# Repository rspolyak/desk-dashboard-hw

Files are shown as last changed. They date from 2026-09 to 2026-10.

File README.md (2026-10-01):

# desk-dashboard-hw

A small ESP32-S3 board that plugs onto the 14-pin header of an **MSP3526** 3.5" IPS
capacitive touchscreen (ST7796 + FT6336U) and turns it into a desk dashboard.
Powered over USB-C (5 V). KiCad 10 project.

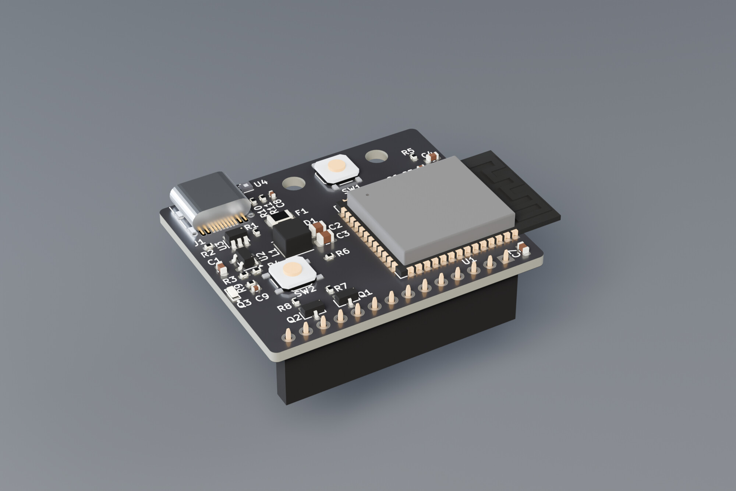
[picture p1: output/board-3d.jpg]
3D render of the board


**Status:** schematic and PCB finished (ERC 0 errors, DRC 0 errors, fully routed).
!NOT TESTED ON ACTUAL HW YET!

## Features
- ESP32-S3-WROOM-1-N16R8 (16 MB flash, 8 MB octal PSRAM), native USB on the USB-C connector
- Plugs straight into the display's 14-pin 2.54 mm header, no cables; two optional M3 standoffs
- Ambient light sensor (ALS-PT19) for automatic backlight control
- SHT40 temperature / humidity sensor on its own I²C bus
- BOOT and RESET buttons
- 5 V to 3.3 V buck (TLV62569), USB ESD protection (USBLC6-2SC6), 1.1 A PTC and TVS on VBUS

## Board
- 41.5 x 35 mm, 2 layers, 1.6 mm, black solder mask, white silkscreen
- The ESP32 antenna overhangs the right board edge by 6 mm (Espressif's preferred placement)
- J2 (display socket) is on the display-facing side; all other parts face outward

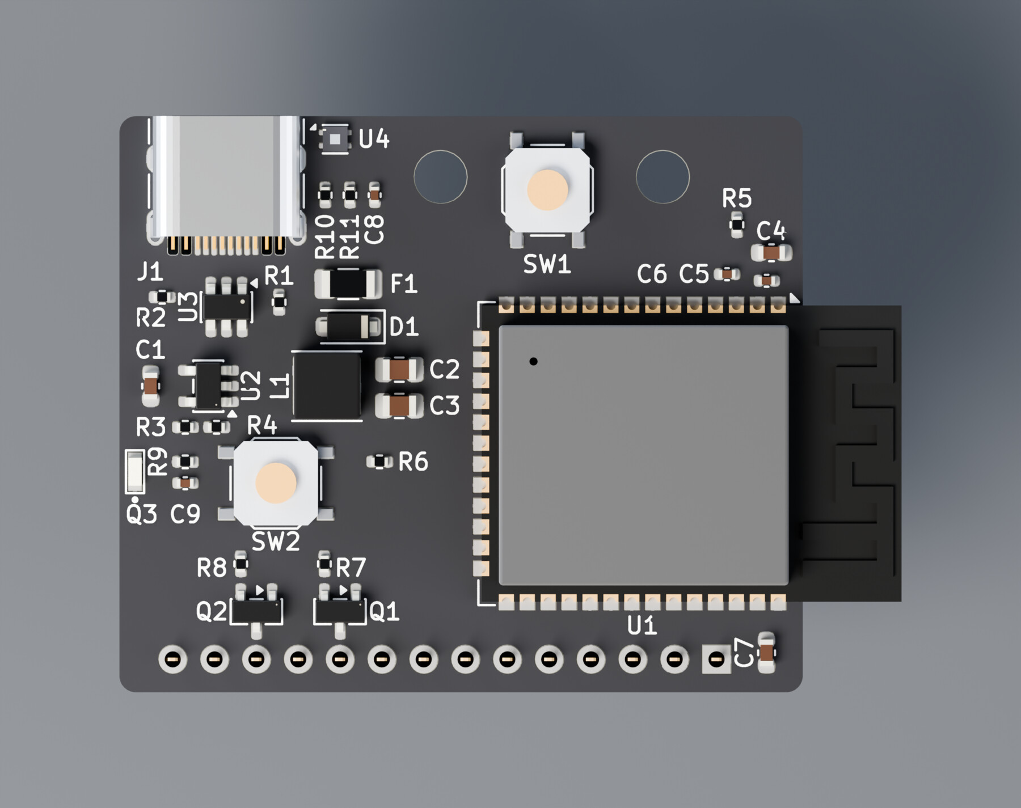
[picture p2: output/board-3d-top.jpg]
Top view of the board with all reference designators


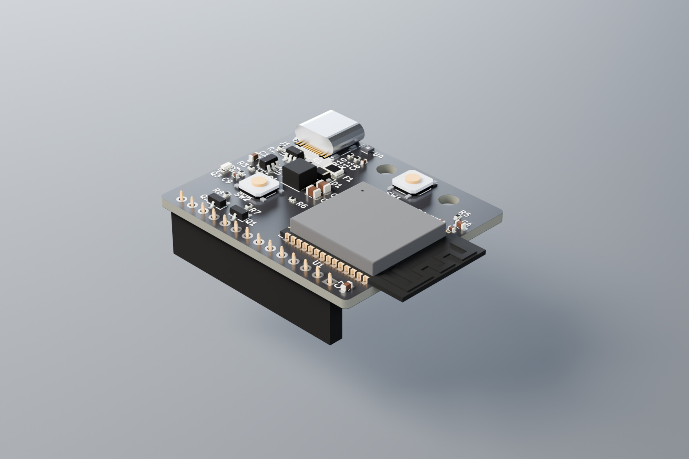
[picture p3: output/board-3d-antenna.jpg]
Side view: J2 display socket underneath and the ESP32 antenna overhanging the board edge


## Design notes
- The display is powered from **5 V**: its LDO also feeds the backlight, which would be dim at 3.3 V.
- The display's touch I²C has 10 k pull-ups to 5 V, so two BSS138 level shifters (Q1 SCL, Q2 SDA)
  keep 5 V away from the ESP32-S3.
- The SHT40 is on a separate I²C controller from the touch panel.
- The light sensor is on ADC1 (ADC2 conflicts with Wi-Fi).

## Parts
All parts were in stock at JLCPCB when the design was finished. Each schematic symbol carries an
`LCSC` field with its part number.

| Ref | Part | LCSC |
|---|---|---|
| U1 | ESP32-S3-WROOM-1-N16R8 | C2913202 |
| U2 | TLV62569DBVR | C141836 |
| U3 | USBLC6-2SC6 | C2687116 |
| U4 | SHT40-AD1B-R2 | C2909890 |
| J1 | USB-C HRO TYPE-C-31-M-12 | C165948 |
| J2 | 1x14 female header, 2.54 mm, 8.5 mm | C2897377 |
| Q1, Q2 | BSS138 | C78284 |
| Q3 | ALS-PT19-315C | C146233 |

Passives, buttons, PTC, TVS and the inductor are listed in the schematic.

## Display
LCDwiki MSP3526 (3.5" IPS, 320x480, ST7796 + FT6336U), sold by several resellers. Check that the
header pin labels match the J2 order above before buying.

## License
MIT, see LICENSE

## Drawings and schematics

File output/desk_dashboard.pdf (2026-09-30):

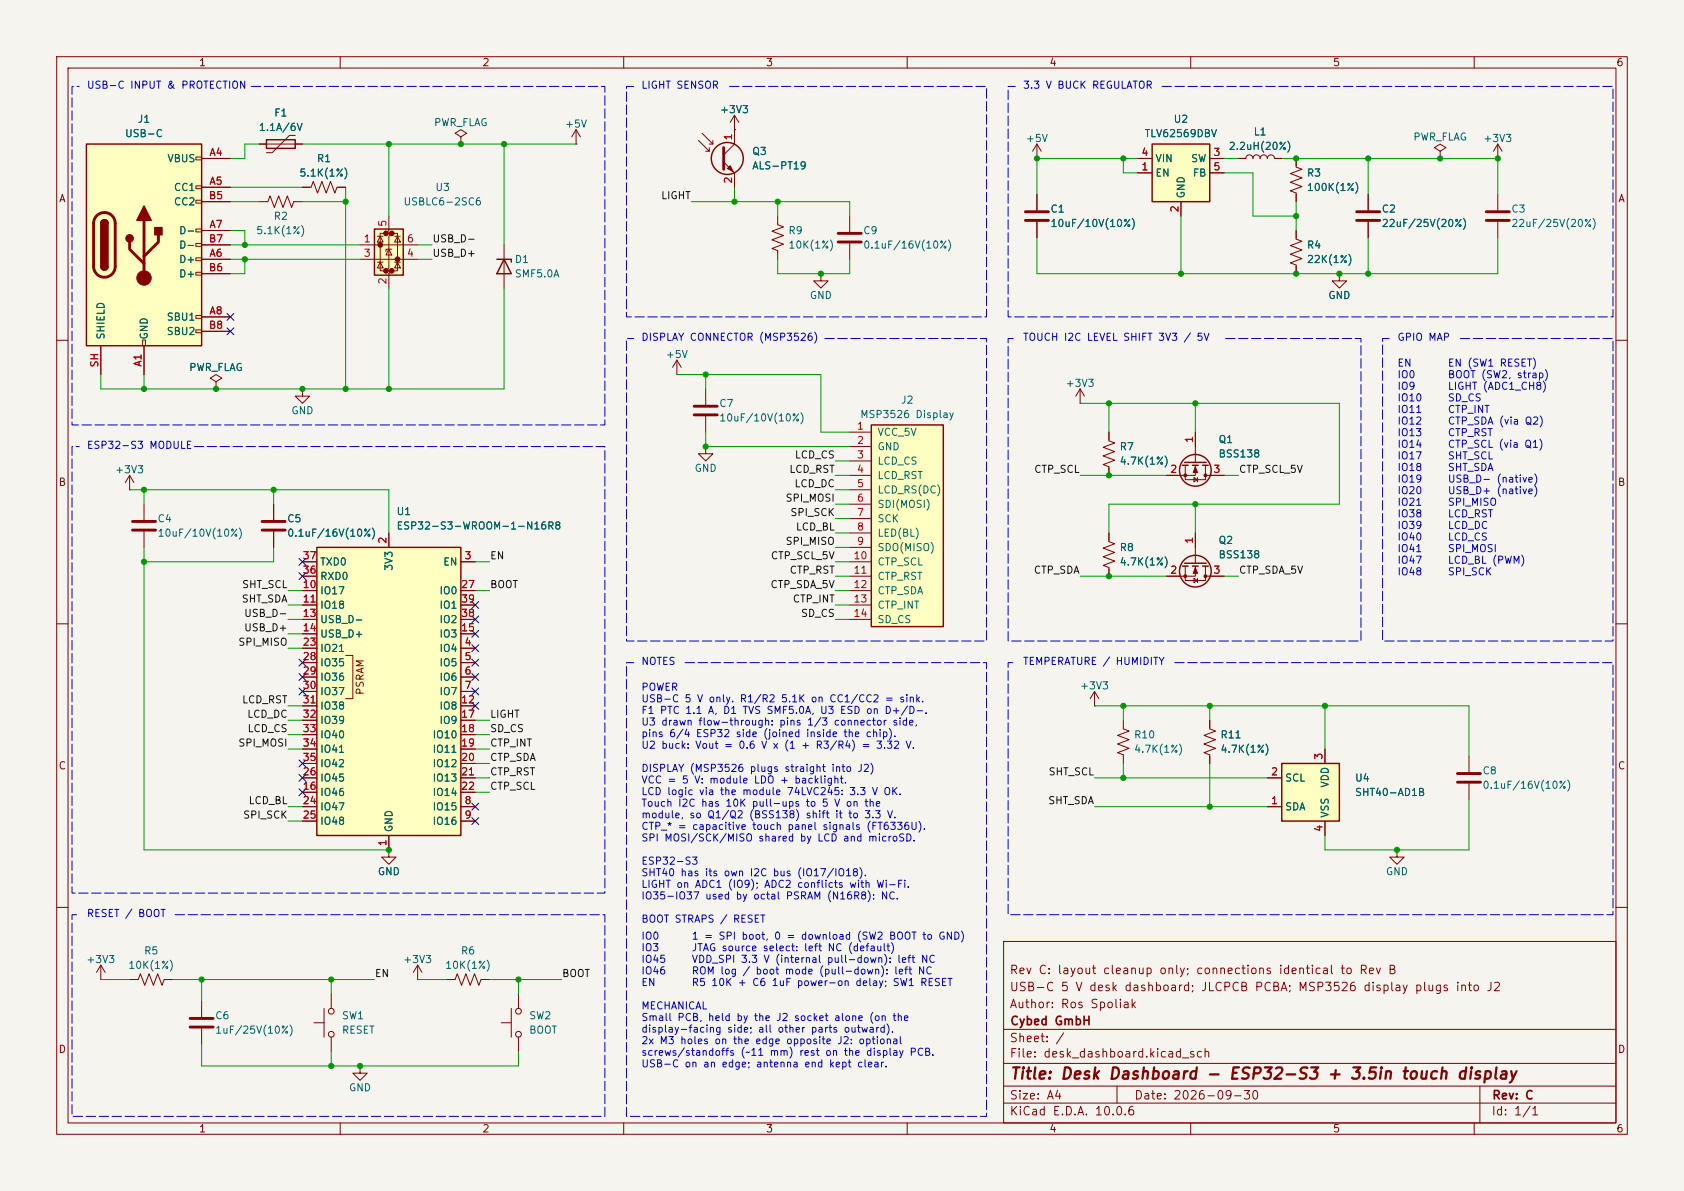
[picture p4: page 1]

EN (SW1 RESET) BOOT (SW2, strap) LIGHT (ADC1_CH8) SD_CS CTP_INT CTP_SDA (via Q2) CTP_RST CTP_SCL (via Q1) SHT_SCL SHT_SDA USB_D- (native) USB_D+ SPI_MISO

IO48 MECHANICAL Small PCB, held by the J2 socket alone (on the display-facing side; all other parts outward). 2x M3 holes on the edge opposite J2: optional

screws/standoffs (~11 mm) rest on the display PCB. USB-C on an edge; antenna end kept clear. POWER USB-C 5 V only. R1/R2 5.1K on CC1/CC2 = sink. F1 PTC 1.1 A, D1 TVS SMF5.0A, U3 ESD on D+/D-. U3 drawn flow-through: pins 1/3 connector side,

pins 6/4 ESP32 side (joined inside the chip). U2 buck: Vout = 0.6 V x (1 + R3/R4) = 3.32 V. DISPLAY (MSP3526 plugs straight into J2) VCC = 5 V: module LDO + backlight. LCD logic via the module 74LVC245: 3.3 V OK. Touch I2C has 10K pull-ups to 5 V on the module, so Q1/Q2 (BSS138) shift it to 3.3 V. CTP_* = capacitive touch panel signals (FT6336U). SPI MOSI/SCK/MISO shared by LCD and microSD. ESP32-S3

SHT40 has its own I2C bus (IO17/IO18). LIGHT on ADC1 (IO9); ADC2 conflicts with Wi-Fi.

IO35-IO37 used by octal PSRAM (N16R8): NC. BOOT STRAPS / RESET

1 = SPI boot, 0 = download (SW2 BOOT to GND) JTAG source select: left NC (default) VDD_SPI 3.3 V (internal pull-down): left NC

ROM log / boot mode (pull-down): left NC
R5 10K + C6 1uF power-on delay; SW1 RESET

Rev C: layout cleanup only; connections identical to Rev B
USB-C 5 V desk dashboard; JLCPCB PCBA; MSP3526 display plugs into J2
Author: Ros Spoliak
Cybed GmbH
Sheet: /
File: desk_dashboard.kicad_sch
Title: Desk Dashboard - ESP32-S3 + 3.5in touch display

Size: A4 | Rev: C
KiCad E.D.A. 10.0.6 | Id: 1/1

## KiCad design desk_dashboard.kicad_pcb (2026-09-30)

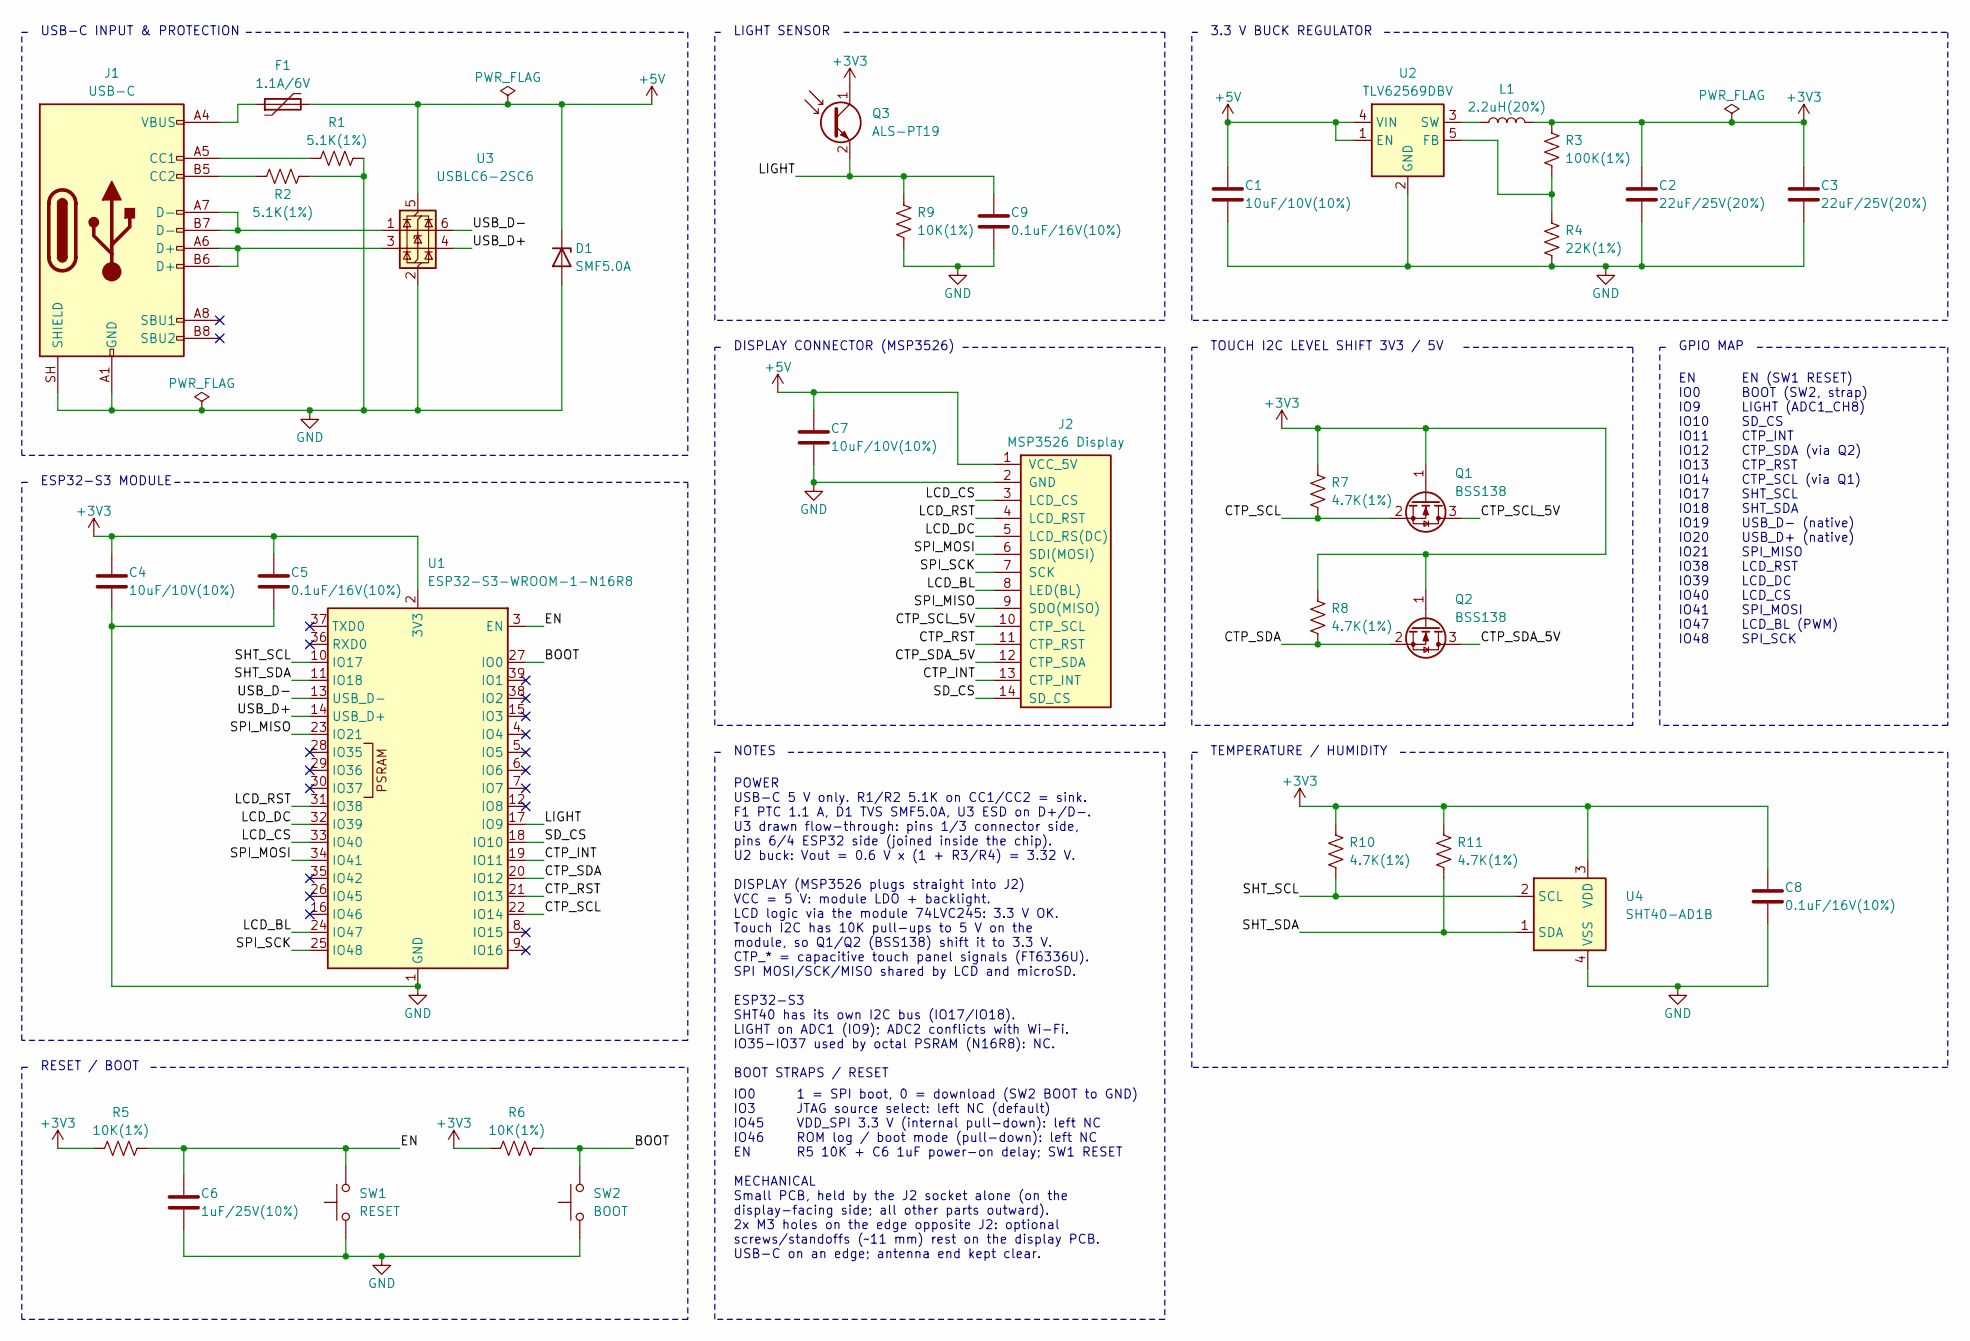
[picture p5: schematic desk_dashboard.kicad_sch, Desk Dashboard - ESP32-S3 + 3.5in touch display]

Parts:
C1, C4, C7: 10uF/10V(10%); C_0603_1608Metric; LCSC C19702
C2, C3: 22uF/25V(20%); C_0805_2012Metric; LCSC C45783
C5, C8, C9: 0.1uF/16V(10%); C_0402_1005Metric; LCSC C1525
C6: 1uF/25V(10%); C_0402_1005Metric; LCSC C52923
D1: SMF5.0A; D_SOD-123F; LCSC C193402
F1: 1.1A/6V; Fuse_1206_3216Metric; LCSC C20801
J1: USB-C; USB_C_Receptacle_HRO_TYPE-C-31-M-12; LCSC C165948
J2: MSP3526 Display; PinSocket_1x14_P2.54mm_Vertical; LCSC C2897377
L1: 2.2uH(20%); L_Sunlord_SWPA4030S; LCSC C36409
Q1, Q2: BSS138; SOT-23; LCSC C78284
Q3: ALS-PT19; Everlight_ALS-PT19; LCSC C146233
R1, R2: 5.1K(1%); R_0402_1005Metric; LCSC C25905
R3: 100K(1%); R_0402_1005Metric; LCSC C25741
R4: 22K(1%); R_0402_1005Metric; LCSC C25768
R5, R6, R9: 10K(1%); R_0402_1005Metric; LCSC C25744
R7, R8, R10, R11: 4.7K(1%); R_0402_1005Metric; LCSC C25900
SW1: RESET; SW_Push_1P1T_XKB_TS-1187A; LCSC C318884
SW2: BOOT; SW_Push_1P1T_XKB_TS-1187A; LCSC C318884
U1: ESP32-S3-WROOM-1-N16R8; ESP32-S3-WROOM-1; LCSC C2913202
U2: TLV62569DBV; SOT-23-5; LCSC C141836
U3: USBLC6-2SC6; SOT-23-6; LCSC C2687116
U4: SHT40-AD1B; Sensirion_DFN-4_1.5x1.5mm_P0.8mm_SHT4x_NoCentralPad; LCSC C2909890

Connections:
+3V3: C2.1, C3.1, C4.1, C5.1, C8.1, L1.2, Q1.1 (G), Q2.1 (G), Q3.1 (C), R3.1, R5.1, R6.1, R7.1, R8.1, R10.1, R11.2, U1.2 (3V3), U4.3 (VDD)
+5V: C1.1, C7.1, D1.1 (K), F1.2, J2.1 (VCC_5V), U2.1 (EN), U2.4 (VIN), U3.5 (VBUS)
/BOOT: R6.2, SW2.2, U1.27 (IO0)
/CTP_INT: J2.13 (CTP_INT), U1.19 (IO11)
/CTP_RST: J2.11 (CTP_RST), U1.21 (IO13)
/CTP_SCL: Q1.2 (S), R7.2, U1.22 (IO14)
/CTP_SCL_5V: J2.10 (CTP_SCL), Q1.3 (D)
/CTP_SDA: Q2.2 (S), R8.2, U1.20 (IO12)
/CTP_SDA_5V: J2.12 (CTP_SDA), Q2.3 (D)
/EN: C6.1, R5.2, SW1.2, U1.3 (EN)
/LCD_BL: J2.8 (LED(BL)), U1.24 (IO47)
/LCD_CS: J2.3 (LCD_CS), U1.33 (IO40)
/LCD_DC: J2.5 (LCD_RS(DC)), U1.32 (IO39)
/LCD_RST: J2.4 (LCD_RST), U1.31 (IO38)
/LIGHT: C9.1, Q3.2 (E), R9.1, U1.17 (IO9)
/SD_CS: J2.14 (SD_CS), U1.18 (IO10)
/SHT_SCL: R10.2, U1.10 (IO17), U4.2 (SCL)
/SHT_SDA: R11.1, U1.11 (IO18), U4.1 (SDA)
/SPI_MISO: J2.9 (SDO(MISO)), U1.23 (IO21)
/SPI_MOSI: J2.6 (SDI(MOSI)), U1.34 (IO41)
/SPI_SCK: J2.7 (SCK), U1.25 (IO48)
/USB_D+: U1.14 (USB_D+), U3.4 (I/O2)
/USB_D-: U1.13 (USB_D-), U3.6 (I/O1)
GND: C1.2, C2.2, C3.2, C4.2, C5.2, C6.2, C7.2, C8.2, C9.2, D1.2 (A), J1.A1 (GND), J1.A12 (GND), J1.B1 (GND), J1.B12 (GND), J1.SH (SHIELD), J2.2 (GND), R1.2, R2.2, R4.2, R9.2, SW1.1, SW2.1, U1.1 (GND), U1.40 (GND), U1.41 (GND), U2.2 (GND), U3.2 (GND), U4.4 (VSS)
unnamed: F1.1, J1.A4 (VBUS), J1.A9 (VBUS), J1.B4 (VBUS), J1.B9 (VBUS)
unnamed: J1.A5 (CC1), R1.1
unnamed: J1.B5 (CC2), R2.1
unnamed: J1.A6 (D+), J1.B6 (D+), U3.3 (I/O2)
unnamed: J1.A7 (D-), J1.B7 (D-), U3.1 (I/O1)
unnamed: R3.2, R4.1, U2.5 (FB)
unnamed: L1.1, U2.3 (SW)

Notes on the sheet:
EN IO0 IO9 IO10 IO11 IO12 IO13 IO14 IO17 IO18 IO19 IO20 IO21 IO38 IO39 IO40 IO41 IO47 IO48
GPIO MAP
ESP32-S3 MODULE
IO0 IO3 IO45 IO46 EN
TOUCH I2C LEVEL SHIFT 3V3 / 5V
3.3 V BUCK REGULATOR
LIGHT SENSOR
TEMPERATURE / HUMIDITY
USB-C INPUT & PROTECTION
1 = SPI boot, 0 = download (SW2 BOOT to GND) JTAG source select: left NC (default) VDD_SPI 3.3 V (internal pull-down): left NC ROM log / boot mode (pull-down): left NC R5 10K + C6 1uF power-on delay; SW1 RESET
NOTES
MECHANICAL Small PCB, held by the J2 socket alone (on the display-facing side; all other parts outward). 2x M3 holes on the edge opposite J2: optional screws/standoffs (~11 mm) rest on the display PCB. USB-C on an edge; antenna end kept clear.
POWER USB-C 5 V only. R1/R2 5.1K on CC1/CC2 = sink. F1 PTC 1.1 A, D1 TVS SMF5.0A, U3 ESD on D+/D-. U3 drawn flow-through: pins 1/3 connector side, pins 6/4 ESP32 side (joined inside the chip). U2 buck: Vout = 0.6 V x (1 + R3/R4) = 3.32 V. DISPLAY (MSP3526 plugs straight into J2) VCC = 5 V: module L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
EN (SW1 RESET) BOOT (SW2, strap) LIGHT (ADC1_CH8) SD_CS CTP_INT CTP_SDA (via Q2) CTP_RST CTP_SCL (via Q1) SHT_SCL SHT_SDA USB_D- (native) USB_D+ (native) SPI_MISO LCD_RST LCD_DC LCD_CS SPI_MOSI LCD_BL (PWM) SPI_SCK
RESET / BOOT
DISPLAY CONNECTOR (MSP3526)

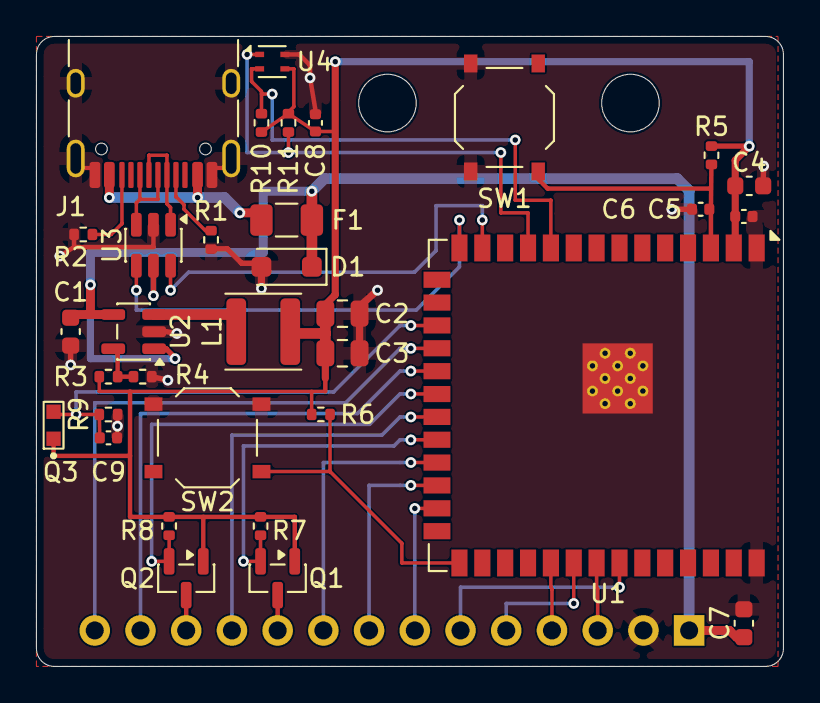
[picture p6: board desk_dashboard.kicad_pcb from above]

Board: 2 copper layers, 41.5 x 35.0 mm, 36 parts (1 on the bottom side), 31 nets.

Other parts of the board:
H1, H2: MountingHole_3.2mm_M3

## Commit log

2026-09-29 Desk dashboard: schematic and PCB
    [desk_dashboard.kicad_pcb, desk_dashboard.kicad_sch]
2026-09-29 Initialize README with project details
    Added detailed project description, features, board specifications, design notes, parts list, display information, and license.
2026-09-29 Add kicad backup folder to gitignore
2026-09-29 Add schematic pdf
2026-09-29 Update README with PCB render
2026-09-30 Clean up schematic text and update schematic pdf
    [desk_dashboard.kicad_sch]
2026-09-30 Add title block and update component positions in PCB design
    [desk_dashboard.kicad_pcb]
2026-09-30 Update README status and testing note
    Clarified status of schematic and PCB, added note about testing.
2026-11-05 Update README with board bring up status
